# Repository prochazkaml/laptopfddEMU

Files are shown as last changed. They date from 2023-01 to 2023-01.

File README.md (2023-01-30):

# laptopfddEMU
AVR based laptop floppy drive emulator

Consists of 2 MCUs:
- ATmega328PB - runs the actual floppy drive emulator
- ATmega16A - serves as a serial terminal, interfaces to 3x 7-segment displays and 5 buttons

The PCB design with the ATmega328PB (TQFP32) is available in the [kicad](/kicad) directory
(note: the design is bad, the electrolytic cap needs to be as close to the MCU as possible, the current placement causes unexpected issues where the MCU resets randomly - 
just solder another cap directly to the MCU's legs from the programmer/serial side, as you've got nice big pads there).

The "PCB design" with the ATmega16A (DIP40) was improvised and cut out on a piece of raw copper PCB with a knife. No designs available for that, I'm afraid.

Apologies for the lack of documentation on this project, but I was improvising almost everything (as I needed to get this project done extra quick)
and did not keep track of progress very well. Consider building this only if you feel brave enough for it.

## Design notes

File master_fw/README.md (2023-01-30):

# fddEMU
An AVR (atmega328p) based floppy drive emulator for PC
<br>

<br>
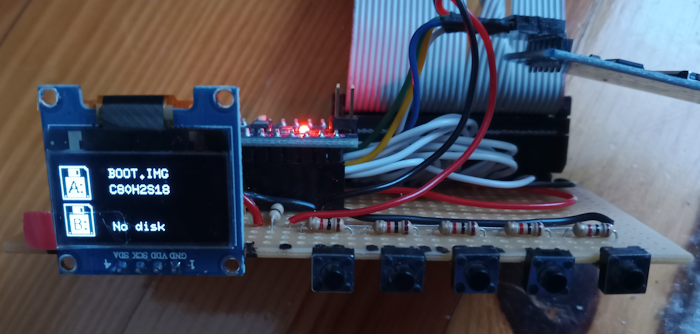
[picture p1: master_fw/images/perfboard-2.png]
fddEMU on perfboard

<br>
<br>
fddEMU is a DIY floppy drive emulator. You can immediately begin testing fddEMU on serial terminal with an arduino nano, an SD adapter that converts 5 volts arduino power supply and signals to 3.3 volts suitable for SD card, an SD card,  and some jumper cables. 
Standalone (using without usb serial connection) require SSD1306 i2c screen, buttons and a 5 volts power supply.
<br><br>

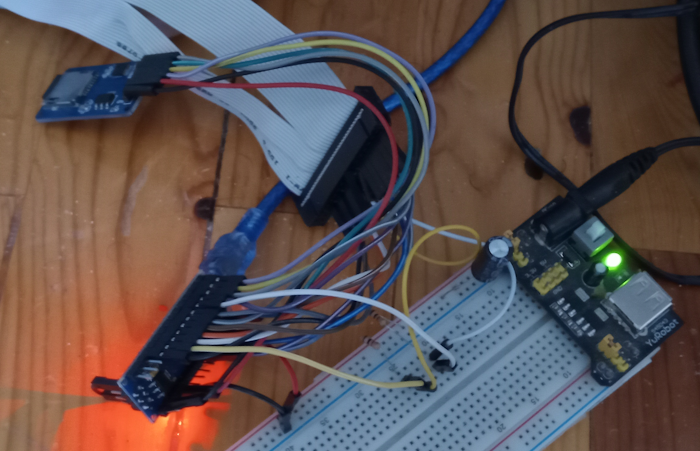
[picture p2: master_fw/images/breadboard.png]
fddEMU on breadboard

<br><br>

**A very compact and configurable PCB design for fddEMU (created by @ikonko)**<br>
Please check [documentation and photos for compact PCB](/master_fw/images/ikonko) for detailed explanation and configuration options. Gerber files are available in [hardware](/hardware) folder.
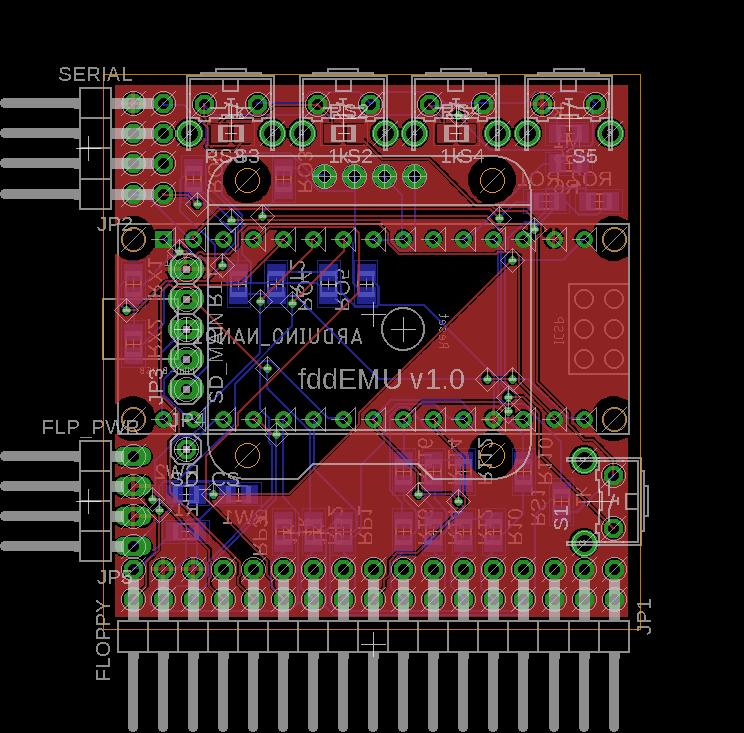
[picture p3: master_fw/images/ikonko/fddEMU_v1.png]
Compact multilayered pcb

<br><br>

**Limitations**
<br>
* fddEMU is not an cycle exact floppy emulator , it is more of a hack (it's a bit slower than actual fdd) but it works because floppy controllers have sensible timeouts and we take advantage of that.
* fddEMU uses MFM encoding (used by HD and DD disks) so there is no FM encoding (used by SD disks) support as of now. But it is possible to implement FM encoding.
* fddEMU uses raw floppy images (images prepared with dd or rawread) does not require or use a MFM file. Converts raw image sectors to MFM on the fly using [ArduinoFDC](https://github.com/dhansel/ArduinoFDC) library.
* fddEMU supports fixed sector size of 512 bytes, other sector sizes are not supported.
* Requires a Floppy Drive Controller (FDC) on the PC side to communicate so it probably wont work with an Amiga.
<br><br>

**Hardware (Required)**
* Arduino Nano or Arduino Pro Micro (UNO will do but button inputs require ADC7, use serial commands instead)
* Micro SD card adapter (converts 5 volts arduino power supply and signals to 3.3 volts)
* A micro SD card (formatted FAT16/32, floppy images in root directory)
* Two 1kOhm resistors for Step (pin 20 of floppy connector) and WriteData (pin 22 of floppy connector). Atmega's internal pullups are not sufficicient for parasitic capacitance of long floppy drive cable
* Male to female jumper wires (for connecting arduino nano pins to FDC ribbon cable)
* Male to male jumper wires (for pullup on step and readdata pins)
<br>

**Hardware (Optional)**
* 0.96" i2c OLED (SSD1306) screen (for output)
* 4 or 5 1kOhm resistors (for making ADC buttons)
* 1 100kOhm resistor (ADC7 has no pullup, so an external pullup required)
* 4 or 5 push buttons (required for ADC input obviously)
* 5 volts power supply (Computer PSU 5v pins or an external PSU can be used)
* Female to female jumper wires (for connecting SD adapter to arduino nano)
* Breadboard or perfboard (for placing pullups and ADC buttons)
<br><br>

**Pin mapping (single drive)**
Arduino Pro Micro   |Arduino Nano   |FDD Ribbon Cable
--------------------|---------------|----------------------
GND                 |GND		    |1	(GND)
RX (PD2)            |D2 (PD2)       |20	(Step pulse)
TX (PD3)            |D3	(PD3)		|18	(Direction)
8  (PB4)            |D4	(PD4)		|16	(Motor on B)
10 (PB6)            |D5	(PD5)		|12	(Drive Select B)
5  (PC6)            |D6	(PD6)		|32	(Select head)
6  (PD7)            |D7	(PD7)		|8	(Index pulse)
4  (PD4)            |D8	(PB0)		|22	(Write data)
9  (PB5)            |D9	(PB1)		|30	(Read data)
7  (PE6)            |A0	(PC0)		|24	(Write enable)
A3 (PF4)            |A1	(PC1)		|26	(Track zero)
24 (PD5 - TXLED)    |A2	(PC2)	    |28	(Write protect)
A1 (PF6)            |A3	(PC3)		|34	(Disk changed)

<br>

**Pin mapping (dual drive)**
Arduino Pro Micro   |Arduino Nano   |FDD Ribbon Cable
--------------------|---------------|----------------------
GND                 |GND		    |1	(GND)
RX (PD2)            |D2 (PD2)       |20	(Step pulse)
TX (PD3)            |D3	(PD3)		|18	(Direction)
8  (PB4)            |D4	(PD4)		|14	(Drive Select A)
10 (PB6)            |D5	(PD5)		|12	(Drive Select B)
5  (PC6)            |D6	(PD6)		|32	(Select head)
6  (PD7)            |D7	(PD7)		|8	(Index pulse)
4  (PD4)            |D8	(PB0)		|22	(Write data)
9  (PB5)            |D9	(PB1)		|30	(Read data)
7  (PE6)            |A0	(PC0)		|24	(Write enable)
A3 (PF4)            |A1	(PC1)		|26	(Track zero)
24 (PD5 - TXLED)    |A2	(PC2)	    |28	(Write protect)
A1 (PF6)            |A3	(PC3)		|34	(Disk changed)

<br>

**Micro SD Adapter connections**
Arduino Pro Micro   |Arduino Nano   |Micro SD adapter
--------------------|---------------|-------------------
A0 (PF7)            |D10 (PB2)  	|CS
16 (PB2)            |D11 (PB3)	    |MOSI
14 (PB3)            |D12 (PB4)		|MISO
15 (PB1)            |D13 (PB5)		|SCK
VCC                 |5V             |VCC
GND                 |GND            |GND

<br>

**0.96" OLED SSD1306 connections**
Arduino Pro Micro   |Arduino Nano   |0.96" OLED SSD1306
--------------------|---------------|-------------------
GND                 |GND            |GND
VCC                 |5V             |VCC
2  (PD1)			|A4			    |SDA
3  (PD0)			|A5			    |SCL

<br><br>

**Resistor ladder for ADC buttons**
<br>
Connected to pin A7 (ADC7) on Arduino Nano or pin A2 (PF5) on Arduino Pro Micro
<br>
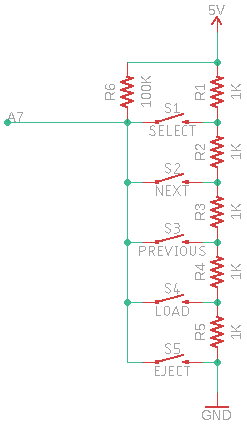
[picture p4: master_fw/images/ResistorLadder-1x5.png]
Resistor Ladder 1x5

<br><br>

**Firmware**
<br>
Download with submodules(u8glib & lufa): `git clone https://github.com/acemielektron/fddEMU --recursive`<br>
If not downloaded with recursive option run (in fddEMU folder): `git submodule update --init --recursive`<br>
Current Makefile assumes avr-gcc and avr-binutils are installed and are in the path, 
avr specific includes are in "/usr/avr/include" (arch) or "/usr/lib/avr/include" (ubuntu) <br>
run `make` to build fddEMU.hex with default options.
<br>
**build options:**
* *GUI:* enables graphical user interface on OLED screen and ADC buttons (enabled default by Makefile). 
* *SERIAL:* enables serial user interface and serial commands.
* *VFFS:* enables virtual disk.
* *DEBUG:* enables debug output on serial.
* *FLIP:* flips the image on OLED screen 180 degrees (enabled default by Makefile).
* *WDT:* enables watchdog timer (enabled default by Makefile).<br><br>
These build options could either be switched on and off from Makefile or commandline 
(eg.: `make DUAL=1 GUI=1 VFFS=1 SERIAL=0 DEBUG=0`).<br>
Flashing the mcu could also be done by Makefile. `make flash` programs "fddEMU.hex" to 
default serial port "/dev/ttyUSB0". If you want to use another serial port assign it to 
PORT variable (eg.: `make flash PORT=/dev/ttyUSB2`).

**Note:** Due to larger bootloader on Atmega32U4 and added code overhead for USB-Serial all features of fddEMU will be avaialble on Atmega32U4

***Warning:*** *Writing > 28K (28672 bytes) firmware to Arduino Pro Micro results in bootloader being overwritten and requires reprogramming the bootloader using external programmer (eg. USBASP). Please check output of avr-size at the end of make process and make sure it is < 28K.*
<br><br>

**How to use**<br>
* fddEMU looks for a boot record on "sector 0" of the image. If the boot record reports that the image is formatted as "FAT1?", sector size is 512, number of heads is 2 and number of tracks and number of sectors are less than 255 the image file is loaded with the settings provided by the boot record. To be able to read these custom FAT12 images host system should support provided number of tracks and sectors. If there is no boot record file size is compared to the standart floppy sizes (1.44M, 1.2M, 720K and 360K), if file size matches one of these sizes it is loaded as raw image.
* Image file must be contiguous for fddEMU to be able to load, if the file is not contiguous an error message will be shown and loading will fail.
* Contiguity check would take long for large files (> 2MB) during this check fddEMU can not be used.
* For booting a host system, on startup fddEmu looks for "BOOT.IMG" on SD card. If there is a "BOOT.IMG" on the SD card fddEMU tries to load this file to drive A. 
* if image file has "read only" attribute set, fddEMU will report "Write Protected" to host system.
* To protect OLED screen fddEMU will put screen to sleep after some idle time, press "S1" (SELECT) button or "S" key inside serial terminal to wake screen up.
* When host is reading/writing one of the emulated drives, BUSY message will be shown on screen and serial, during this time fddEMU will not respond to input. *Warning: fddEMU will not put the screen to sleep while drive is active. If there is a hardware or software problem causing an emulated drive to go continuously active, OLED screen might get damaged.*
<br><br>

**How to use (GUI button interface)**
* S1: Load Virtual Disk
* S2: Next
* S3: Previous
* S4: Open file selection Menu / Load selected file
* S5: Eject selected disk / Cancel loading file
<br>
On the main screen, drive 0 "A" and -if enabled- drive 1 "B" are displayed. To use any of the functions a drive must first be selected through "S2" or "S3" buttons.<br>
After a drive is selected:<br>
"S1" button: in main status screen, if virtual disk is enabled, loads the virtual disk to selected drive.<br>
"S2" button: in main status screen selects drive down, in file selection menu selects file down.<br>
"S3" button: in main status screen selects drive up, in file selection menu selects file up.<br>
"S4" button: in main status screen opens file selection menu, in file selection menu loads the selected image file to the selected drive.<br>
"S5" button: in main status screen ejects image file loaded to the selected drive, in file section menu cancels file selection and returns to main status screen.
<br><br>

**How to use (Serial interface)**
<br>
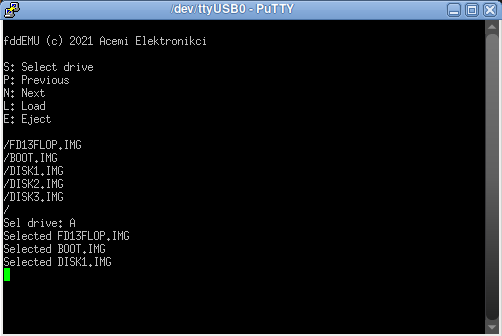
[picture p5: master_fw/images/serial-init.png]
initial serial output

<br><br>
fddEMU serial interface is used through keys 
* S: Select
* N: Next file
* P: Previous file
* L: Load selected file
* E: Eject selected disk / Cancel loading file
<br>
To use any of the functions a drive must first be selected through "S" key then serial terminal will report "Sel drive: A" or if drive B is selected "Sel drive: B".<br>
After a drive is selected:<br>
"S" key: shows serial status information and selects next drive.<br>
"N" key: selects next image file. If virtul disk is enabled and if the last file in the directory is reached selects virtual disk .<br>
"P" key: selects the previous image file. If the first file is selected, this file is reselected.<br>
"L" key: loads selected image file to the selected drive.<br>
"E" key: ejects image file loaded to selected drive. If pressed during file selection, cancels file selection.
<br><br>

**How to use through host system (Virtual Disk)**
<br>
-if virtual disk (VFFS) is enabled and loaded- Virtual disk root directory contains a "DISKS" directory, a "DRVA.TXT" file and if DUAL drives enabled a "DRVB.TXT" file. If an SD card is inserted "DISKS" directory contains the file listing of inserted SD card's root directory otherwise it will be empty. "DRVA.TXT" would contain name of the image file loaded the "drive 0" and "DRVB.TXT" would contain name of the image file loaded to "drive 1". Writing the name of an image file to either "DRVA.TXT" or "DRVB.TXT" would result loading requested image file to respective emulated drive upon host releasing the drive. However disk write cache might interfere writing into these files and a cache flush might be required.
<br><br>

**Troubleshooting**
* To test fddEMU or any other floppy drive emulator a Floppy Drive Controller (FDC) is very useful. Unfortunately new computers usually don't come with a FDC. Thankfully we already have a very good FDC that generates the precise debug information we need: the [ArduinoFDC](https://github.com/dhansel/ArduinoFDC). A direct pin to pin connection from fddEMU to ArduinoFDC works, if using shorter jumper wires external pullups are not necessary.
* If using a floppy drive ribbon cable make sure of external pullup resistors to +5V on Step (Pin 20 on floppy connector) and WriteData (pin 22 on floppy connector) pins.
* If WiteData pin (pin 22 on floppy connector) is disconnected or does not have sufficient external pullup fddEMU might hang up while reading data from host, which might cause a static image on screen. To protect the screen currently a watchdog timer of 8 seconds is set (which is the longest duration for watchdog timer). If mcu (arduino) can't access SD card after reset remove the sd card, wait a few seconds, reinsert the SD card then reset the arduino.

**Acknowledgements**
<br>
* [ArduinoFDC](https://github.com/dhansel/ArduinoFDC) by [David Hansel](https://github.com/dhansel). fddEMU uses a modified ArduinoFDC library renamed to avrFlux for communicating with FDC.
* [Petit FAT FS](https://github.com/greiman/PetitFS) by [Chan](http://elm-chan.org/fsw/ff/00index_p.html) adapted for hardware SPI by [Bill Greiman](https://github.com/greiman). fddEMU uses a modified Petit FAT FS.
* [rjhcoding.com/avrc-sd-interface](http://rjhcoding.com/avrc-sd-interface-1.php) Great tutorial for using SD card with AVR.
* [u8glib](https://github.com/olikraus/u8glib) Very useful for incorporating SSD1306 and can easily be used with various displays.
* [lufa](https://github.com/abcminiuser/lufa) Lightweight USB Framework for AVRs
<br><br>

**Releases**
<br>
* [fddEMU releases](https://github.com/acemielektron/fddEMU/releases)
<br><br>

**Note:**  Please report any errors on [github issues for fddEMU](https://github.com/acemielektron/fddEMU/issues). Suggestions for improvements and feedback could be posted on [discussions](https://github.com/acemielektron/fddEMU/discussions) or [fddEMU blog page](http://acemielektronikci.blogspot.com/2021/10/fddemu-disket-surucu-emulatoru.html) Although the blog page is in turkish, feel free to write comments either in turkish or english.
<br><br>

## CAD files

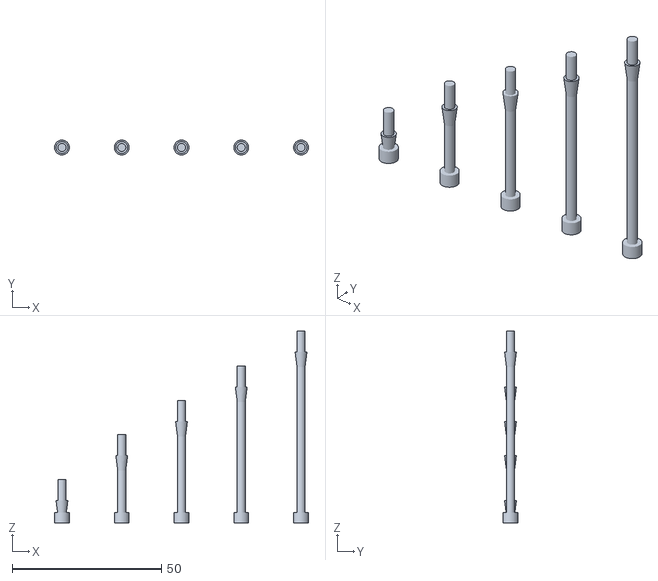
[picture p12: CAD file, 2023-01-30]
3d/floppyemubutton.stl
85.0 x 5.00 x 64.2

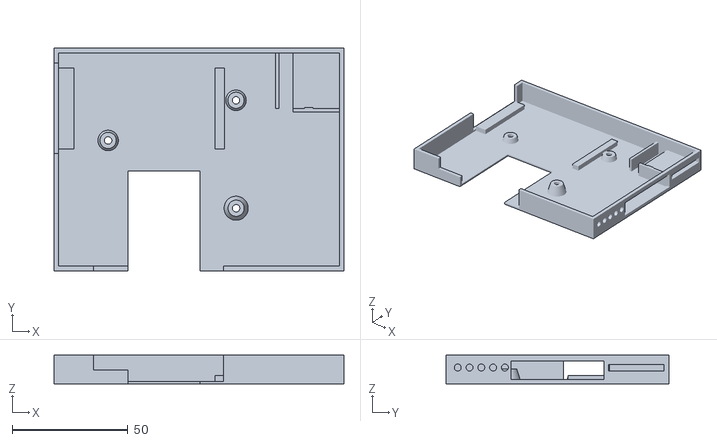
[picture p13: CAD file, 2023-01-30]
3d/floppyemu.stl
125.0 x 96.0 x 12.5

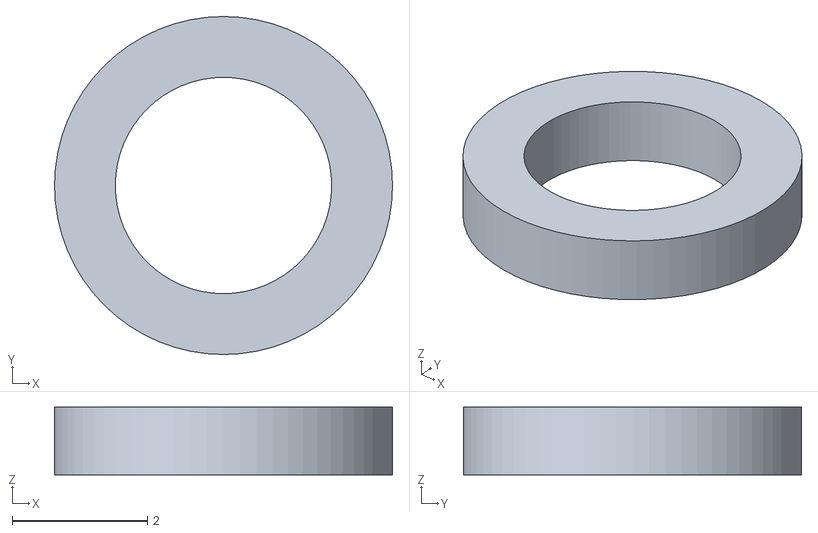
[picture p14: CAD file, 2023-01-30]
3d/floppyemuscrew.stl
5.00 x 5.00 x 1.00

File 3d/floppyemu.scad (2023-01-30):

led_w = 40;
led_h = 8;
led_z = 2;

sd_w = 24;
sd_h = 2.8;
sd_d = 32 - 4;
sd_z = 5.7;

sd_stop_d = 1.5;

sd_pin_d = 6;

body_w = 125;
body_d = 96;

pcb_w = 83.0580;
pcb_d = 34.9200;

pcb_off_x = 2;
pcb_off_y = 8.5;

pcb_front_standoff_w = 6.6040;
pcb_back_standoff_x = 11.6000;
pcb_back_standoff_w = 4.0000;

pcb_h1_x = 21.3360;
pcb_h1_y = 3.6360;

pcb_h2_x = pcb_w - 6.6040;
pcb_h2_y = pcb_d - 13.9700;

dpcb_cutout_x = 32;
dpcb_cutout_w = 31;
dpcb_cutout_h = 43;

dpcb_screw_x = 46.5;
dpcb_screw_y = 27;

$fn = 64;

module maincutout() {
	difference() {
		union() {
			translate([2, 2, 1]) cube([body_w - 4, body_d - 4, 12.51]);
			translate([17, -.01, 3]) cube([body_w - 17 - 52, 2.02, 12.51]);
			translate([dpcb_cutout_x + dpcb_cutout_w - .01, -.01, 1]) cube([(body_w - dpcb_cutout_x - dpcb_cutout_w) - 51.99, 2.02, 10]);
		}
		children();
	}
	
/*	difference() {
		for(i = [0 : 10]) hull() {
			translate([10, 8 + i * (body_d - 16) / 10]) cylinder(h = 2.01, d = 5, center = true);
			
			translate([body_w - 8, 8 + i * (body_d - 16) / 10]) cylinder(h = 2.01, d = 5, center = true);
		}
		
		children();
	}*/
}
/*

translate([pcb_off_x, body_d - pcb_off_y - pcb_d, 3.75]) difference() {
	cube([pcb_w, pcb_d, 1.6]);
	translate([pcb_h1_x, pcb_h1_y]) cylinder(d = 3.2, h = 4, center = true);
	translate([pcb_h2_x, pcb_h2_y]) cylinder(d = 3.2, h = 4, center = true);
}
*/

difference() {
	cube([body_w, body_d, 12.5]);
	
	// PCB cutout
	translate([-.01, body_d - pcb_off_y - pcb_d - 2, 2]) cube([2.02, pcb_d + 4, 20]);

	// Daughter PCB cutout (otherwise it wouldn't fit)
	translate([dpcb_cutout_x, -.01, -.01]) cube([dpcb_cutout_w, dpcb_cutout_h, 12.51]);
	
	maincutout() {
		// PCB front standoff
		translate([pcb_off_x, body_d - pcb_off_y - pcb_d]) cube([pcb_front_standoff_w, pcb_d, 7.5 / 2]);

		// PCB back standoff
		translate([pcb_off_x + pcb_w - pcb_back_standoff_x - pcb_back_standoff_w, body_d - pcb_off_y - pcb_d]) cube([pcb_back_standoff_w, pcb_d, 7.5 / 2]);
		
		// PCB screw posts
		translate([pcb_off_x + pcb_h1_x, body_d - pcb_off_y - pcb_d + pcb_h1_y]) cylinder(d1 = 12, d2 = 7, h = 7.5, center = true);
		
		translate([pcb_off_x + pcb_h2_x, body_d - pcb_off_y - pcb_d + pcb_h2_y]) cylinder(d1 = 12, d2 = 7, h = 7.5, center = true);
		
		// Daughter PCB screw post
		translate([body_w - dpcb_screw_x, dpcb_screw_y]) cylinder(d1 = 15, d2 = 7, h = (8 - 1.6) * 2, center = true);
		
		// SD bottom plate
		translate([body_w - sd_d + sd_pin_d, body_d - 2 - sd_w, 0]) cube([sd_d - sd_pin_d, sd_w, sd_z]);
		
		// SD back wall
		translate([body_w - sd_d - sd_stop_d, body_d - 2 - sd_w, 0]) cube([sd_stop_d, sd_w, sd_z + sd_h]);
		
		// SD side wall
		translate([body_w - sd_d + sd_pin_d, body_d - 2 - sd_w - sd_stop_d, 0]) difference() {
			cube([sd_d - sd_pin_d, sd_stop_d, sd_z + sd_h]);

			// Wire cutout

//			translate([sd_stop_d, -.01, 0]) cube([sd_pin_d, (body_d - 2 - sd_w) - (body_d / 2 + 40 / 2) + .02, sd_z]);
		}
		
		// SD lock notch
		translate([body_w - sd_d + 10.9, body_d - 2 - sd_w, 0]) cube([3.75, .5, sd_z + sd_h]);
	}
	
	// PCB screw holes
	translate([pcb_off_x + pcb_h1_x, body_d - pcb_off_y - pcb_d + pcb_h1_y]) {
		cylinder(d = 3.2, h = 7.51, center = true);
		cylinder(d = 6.5, $fn = 6, h = 5.5, center = true);
	}
	
	translate([pcb_off_x + pcb_h2_x, body_d - pcb_off_y - pcb_d + pcb_h2_y]) {
		cylinder(d = 3.2, h = 7.51, center = true);
		cylinder(d = 6.5, $fn = 6, h = 5.5, center = true);		
	}

	// Daughter PCB screw hole
	translate([body_w - dpcb_screw_x, dpcb_screw_y]) {
		cylinder(d = 3.2, h = (8 - 1.6) * 2.01, center = true);
		cylinder(d = 6.5, $fn = 6, h = 10, center = true);		
	}
	
	// LED display front cutout
	translate([body_w - 2.01, body_d / 2 - led_w / 2, led_z]) cube([2.02, led_w, led_h]);
	
	// SD card front cutout
	translate([body_w - 2.01, body_d - 2 - sd_w, sd_z]) cube([2.02, sd_w, sd_h]);
	
	// Button front cutout
	for(i = [0 : 4]) translate([body_w - 1, 5 + i * 2.54 * 2, sd_z + sd_h / 2]) rotate([0, 90, 0]) cylinder(h = 2.01, center = true, d = 3);
	
//	cube([94, body_d, 13]);
//	cube([120, 65, 13]);
}

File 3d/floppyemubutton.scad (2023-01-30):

$fn = 64;

sizes = [7.5, 22.6, 34, 45.5, 57.2];

for(i = [0 : len(sizes) - 1]) translate([i * 20, 0]) {
	difference() {
//		cylinder(h = sizes[i], d = 5);
		cylinder(h = 3.5, d = 5);
		translate([0, 0, -.01]) cylinder(h = 2.5, d = 3.75);
	}
	
	translate([0, 0, sizes[i] - 5]) cylinder(h = 5, d1 = 2.7, d2 = 4);
	
	translate([0, 0, 3.5]) cylinder(h = sizes[i] + 3.5, d = 2.7);
}

//translate([0, 0, 3.5]) cylinder(h = 59 + 1.5, d = 2.8);
//translate([0, 0, 3.5]) cylinder(h = 35.4 + 1.5, d = 2.8);

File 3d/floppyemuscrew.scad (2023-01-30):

$fn = 64;

difference() {
	cylinder(h = 1, d = 5, center = true);
	cylinder(h = 1.01, d = 3.2, center = true);
}

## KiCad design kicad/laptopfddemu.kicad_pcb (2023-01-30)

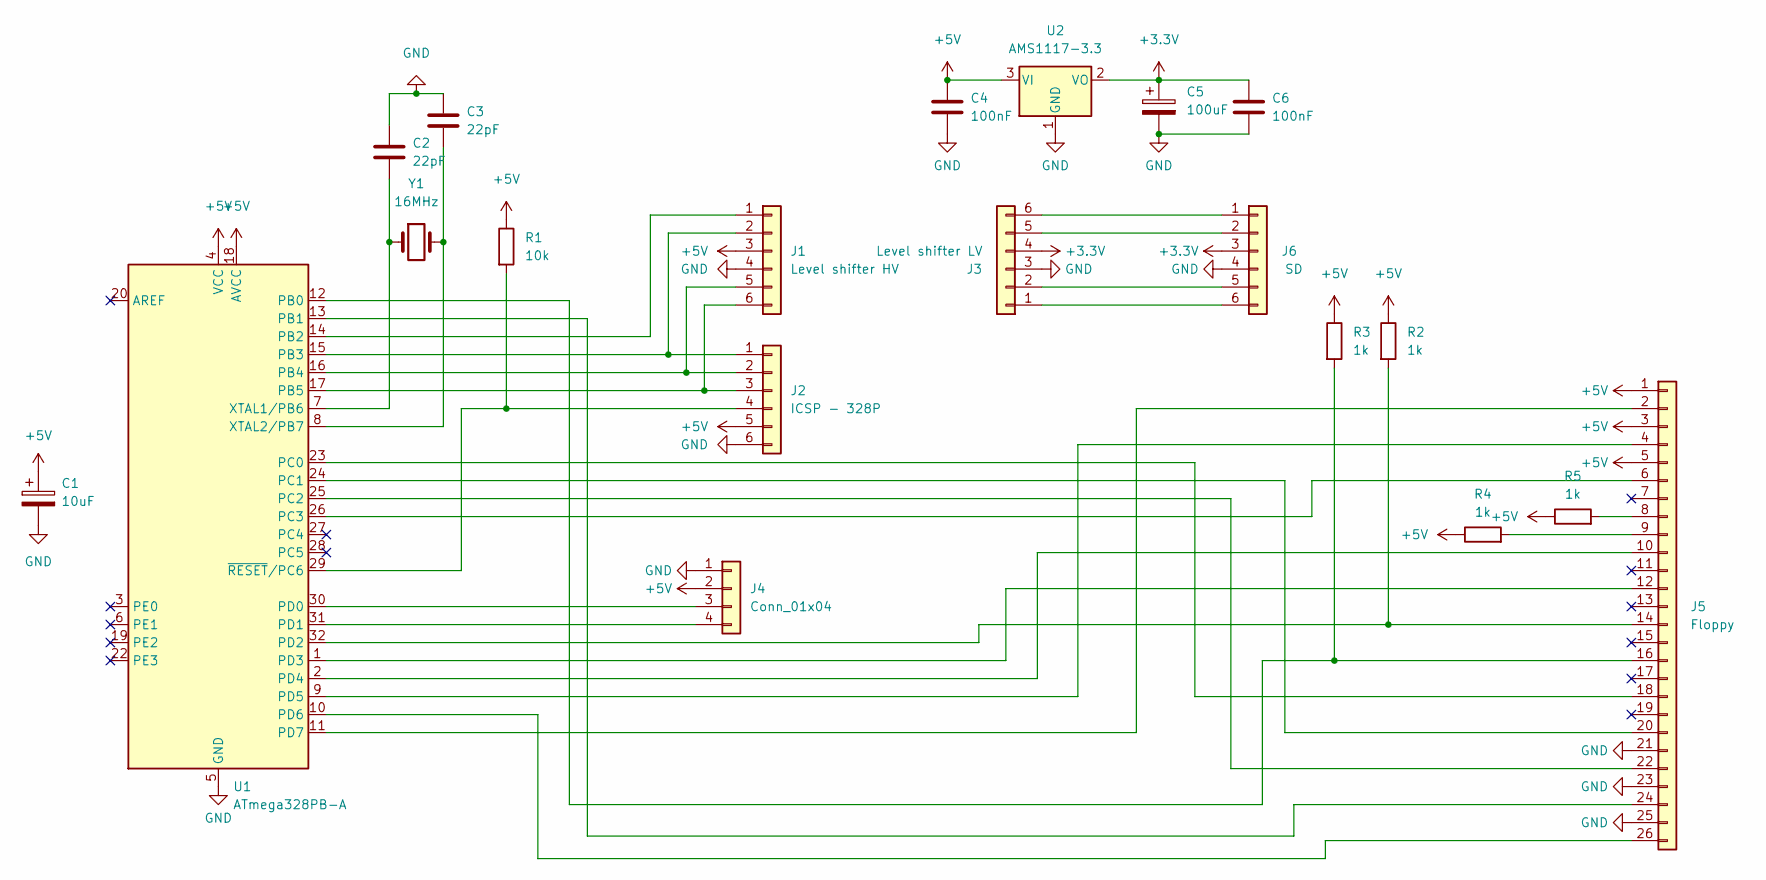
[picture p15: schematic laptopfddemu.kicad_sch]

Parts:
C1: 10uF; CP_Radial_D5.0mm_P2.50mm
C2, C3: 22pF; C_Disc_D7.0mm_W2.5mm_P5.00mm
C4, C6: 100nF; C_Disc_D7.0mm_W2.5mm_P5.00mm
C5: 100uF; CP_Radial_D5.0mm_P2.50mm
J1: Level shifter HV; PinHeader_1x06_P2.54mm_Vertical
J2: ICSP - 328P; PinHeader_1x06_P2.54mm_Vertical
J3: Level shifter LV; PinHeader_1x06_P2.54mm_Vertical
J4: Conn_01x04; PinHeader_1x04_P2.54mm_Vertical
J5: Floppy; TE_2-84953-6_1x26-1MP_P1.0mm_Horizontal
J6: SD; PinHeader_1x06_P2.54mm_Vertical
R1: 10k; R_Axial_DIN0207_L6.3mm_D2.5mm_P10.16mm_Horizontal
R2, R3, R4, R5: 1k; R_Axial_DIN0207_L6.3mm_D2.5mm_P10.16mm_Horizontal
U1: ATmega328PB-A; TQFP-32_7x7mm_P0.8mm
U2: AMS1117-3.3; SOT-223-3_TabPin2
Y1: 16MHz; Crystal_HC49-U_Vertical

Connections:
+3.3V: C5.1, C6.1, J3.4, J6.3, U2.2 (VO)
+5V: C1.1, C4.1, J1.3, J2.5, J4.2, J5.1, J5.3, J5.5, R1.1, R2.1, R3.1, R4.1, R5.1, U1.4 (VCC), U1.18 (AVCC), U2.3 (VI)
GND: C1.2, C2.1, C3.1, C4.2, C5.2, C6.2, J1.4, J2.6, J3.3, J4.1, J5.21, J5.23, J5.25, J5.MP, J6.4, U1.5 (GND), U1.21 (GND), U2.1 (GND)
unnamed: C2.2, U1.7 (XTAL1/PB6), Y1.1
unnamed: C3.2, U1.8 (XTAL2/PB7), Y1.2
unnamed: J1.1, U1.14 (PB2)
unnamed: J1.2, J2.1, U1.15 (PB3)
unnamed: J1.5, J2.2, U1.16 (PB4)
unnamed: J1.6, J2.3, U1.17 (PB5)
unnamed: J2.4, R1.2, U1.29 (~RESET/PC6)
unnamed: J3.1, J6.6
unnamed: J3.2, J6.5
unnamed: J3.5, J6.2
unnamed: J3.6, J6.1
unnamed: J4.3, U1.30 (PD0)
unnamed: J4.4, U1.31 (PD1)
unnamed: J5.2, U1.11 (PD7)
unnamed: J5.4, U1.9 (PD5)
unnamed: J5.6, U1.26 (PC3)
unnamed: J5.8, R5.2
unnamed: J5.9, R4.2
unnamed: J5.10, U1.2 (PD4)
unnamed: J5.12, U1.1 (PD3)
unnamed: J5.14, R2.2, U1.32 (PD2)
unnamed: J5.16, R3.2, U1.12 (PB0)
unnamed: J5.18, U1.23 (PC0)
unnamed: J5.20, U1.24 (PC1)
unnamed: J5.22, U1.25 (PC2)
unnamed: J5.24, U1.13 (PB1)
unnamed: J5.26, U1.10 (PD6)

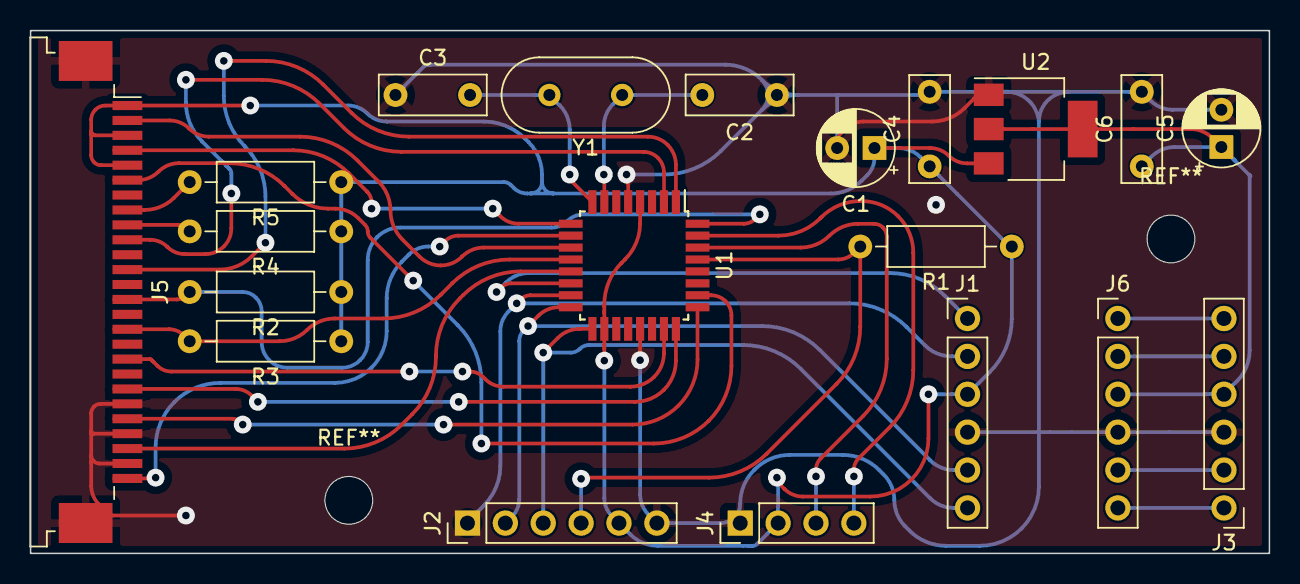
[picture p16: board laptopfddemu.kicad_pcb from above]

Board: 2 copper layers, 83.1 x 35.1 mm, 20 parts (0 on the bottom side), 30 nets.

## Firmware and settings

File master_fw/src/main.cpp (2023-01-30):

// -----------------------------------------------------------------------------
// fddEMU "Floppy Disk Drive Emulator"
// Copyright (C) 2021 Acemi Elektronikci
//
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

#include "fddEMU.h"
#include "FloppyDrive.h"
#include "serial/SerialUI.h"
#include <avr/io.h>
#include "petitfs/pff.h"
#include "DiskFile.h"

int main(void)
{
#ifdef DDRE
	DDRE = 0;
	PORTE = 0xF;
#endif

#if ENABLE_WDT
	wdt_enable(WDTO_8S);
#endif  //ENABLE_WDT
#if ENABLE_SERIAL || DEBUG
	Serial.init(115200);
	ser.intro();
#endif //ENABLE_SERIAL || DEBUG
//	if (sdfile.sdInitialized)
//		drive[0].load((char *)s_bootfile);   //if there is "BOOT.IMG" on SD load it
#if ENABLE_VFFS
//	else
//		drive[0].loadVirtualDisk();
#endif //ENABLE_VFFS
	for(;;)
	{
	#if ENABLE_WDT
		wdt_reset();
	#endif //ENABLE_WDT
		if (ds.isDrvChanged())
		{
			uint8_t selectedDrive = ds.getDriveSel();
		#if ENABLE_GUI
			disp.showDriveBusy(selectedDrive);
		#endif //ENABLE_GUI
		#if ENABLE_SERIAL || DEBUG
			Serial.print_P(str_busy); //very short message, take too long and get drive read errors
		#endif //#if ENABLE_SERIAL || DEBUG
			drive[selectedDrive - 1].run();
		#if ENABLE_VFFS
			vffs.loadImage(); //check if a drive is flagged for vffs load and load if it is
		#endif //ENABLE_VFFS
		#if ENABLE_GUI
			disp.showDriveIdle();
		#endif //ENABLE_GUI
		#if ENABLE_SERIAL || DEBUG
			Serial.print_P(str_idle);
		#endif //ENABLE_SERIAL || DEBUG
		}
	#if ENABLE_SERIAL
		if (rxReady) ser.readRx();
	#endif //ENABLE_SERIAL
	#if ENABLE_GUI
		if (adcReady) disp.buttonAction(abtn.read());
		disp.update();
	#endif //ENABLE_GUI
	}
}

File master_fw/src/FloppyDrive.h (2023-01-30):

// -----------------------------------------------------------------------------
// This file is part of fddEMU "Floppy Disk Drive Emulator"
// Copyright (C) 2021 Acemi Elektronikci
//
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
#ifndef FLOPPYDRIVE_H
#define FLOPPYDRIVE_H

#include "FloppyDisk.h"
#include <stdint.h>

#if defined (__AVR_ATmega328P__) || defined (__AVR_ATmega328PB__)
// -------------------------------  Pin assignments for Arduino UNO/Nano/Pro Mini (Atmega328p)  ------------------------------
//PORTD
#define PIN_STEP      2
#define REG_STEP			PIND
#define PIN_STEPDIR   3
#define REG_STEPDIR		PIND
#define PIN_MOTORA    4
#define REG_MOTORA		PIND
#define PIN_SELECTA   5
#define REG_SELECTA		PIND
#define PIN_SIDE      6
#define REG_SIDE			PIND
#define PIN_INDEX     7
#define DDR_INDEX			DDRD

//PORTB
#define PIN_READDATA  0
#define DDR_READDATA	DDRB
#define PIN_WRITEDATA 1
#define DDR_WRITEDATA DDRB
//rest of PORTB pins are SPI

//PORTC
#define PIN_WRITEGATE 0
#define REG_WRITEGATE PINC
#define PIN_TRACK0    1
#define DDR_TRACK0 		DDRC
#define PIN_WRITEPROT 2
#define DDR_WRITEPROT DDRC
#define PIN_DSKCHANGE 3
#define DDR_DSKCHANGE DDRC


// -------------------------------  Pin assignments for Arduino UNO/Nano/Pro Mini (Atmega328p)  ------------------------------
#elif defined (__AVR_ATmega32U4__)
// -------------------------------  Pin assignments for Arduino (Atmega32U4)  ------------------------------
//PORTD PD0(SCL) and PD1(SDA) I2C pins (D2 and D3 on pro micro)
//PORTB PB0(SS), PB1(SCK), PB2(MISO), PB3(MOSI) SPI pins (D17, D15, D14, D16)  D17->TX led

//Unchangeable pins ICP&OCP for timer1
#define PIN_READDATA    4   //PD4 must be pin4 (ICP for timer1)
#define DDR_READDATA		DDRD
#define PIN_WRITEDATA   5   //PB5 must be pin9 (OCP for timer1)
#define DDR_WRITEDATA		DDRB
//Pin Change Interrupt pins
#define PIN_MOTORA      4   //PB4-PCINT4-pin8
#define REG_MOTORA			PINB
#define PIN_SELECTA     6   //PB6-PCINT6-pin10
#define REG_SELECTA			PINB
//External Interrupt pins
#define PIN_STEP        2   //PD2-INT2-RX1 will use external interrupt 2
#define REG_STEP				PIND
//Changeable pins
#define PIN_STEPDIR     3   //PD3-INT3-TX1
#define REG_STEPDIR			PIND
#define PIN_SIDE        6   //PC6-pin5
#define REG_SIDE				PINC
#define PIN_INDEX       7   //PD7-pin6
#define DDR_INDEX				DDRD
#define PIN_WRITEGATE   6   //PE6-INT6-pin7
#define REG_WRITEGATE		PINE
#define PIN_TRACK0      4   //PF4-pinA3
#define DDR_TRACK0			DDRF
#define PIN_WRITEPROT   5   //PD5-pin24-TXLED
#define DDR_WRITEPROT		DDRD
#define PIN_DSKCHANGE   6   //PF6-pinA1
#define DDR_DSKCHANGE		DDRF
//SS pin for SD card is PF7-pinA0 for atmega32u4 (Arduino pro micro)
//SS pin is set in "pffArduino.h" to change the pin
//also changing the macros in "pffArduino.h" is required.

// -------------------------------  Pin assignments for Arduino (Atmega32U4)  ------------------------------
#endif //defined (__AVR_ATmega32U4__)

//Output commands
#define SET_INDEX_LOW()    (DDR_INDEX |= (1 << PIN_INDEX))
#define SET_INDEX_HIGH()   (DDR_INDEX &= ~(1 << PIN_INDEX))
#define SET_TRACK0_LOW()    (DDR_TRACK0 |= (1 << PIN_TRACK0))
#define SET_TRACK0_HIGH()   (DDR_TRACK0 &= ~(1 << PIN_TRACK0))
#define SET_DSKCHANGE_LOW()    (DDR_DSKCHANGE |= (1 << PIN_DSKCHANGE))
#define SET_DSKCHANGE_HIGH()   (DDR_DSKCHANGE &= ~(1 << PIN_DSKCHANGE))
#define SET_WRITEPROT_LOW()    (DDR_WRITEPROT |= (1 << PIN_WRITEPROT))
#define SET_WRITEPROT_HIGH()   (DDR_WRITEPROT &= ~(1 << PIN_WRITEPROT))

//Inputs
#define IS_WRITE()          ( !(REG_WRITEGATE & (1 << PIN_WRITEGATE)) )
#define SIDE()              (REG_SIDE & (1 << PIN_SIDE))
#define STEPDIR()           (REG_STEPDIR & (1 << PIN_STEPDIR))
#define IS_STEP()           ( !(REG_STEP & (1 << PIN_STEP)) )
#define IS_SELECTA()        ( !(REG_SELECTA & (1 << PIN_SELECTA)) )
#define IS_MOTORA()         ( !(REG_MOTORA & (1 << PIN_MOTORA)) )
//Two drive mode requires SELECT and MOTOR pins combined trough an AND gate
//if two drive mode is enabled SELECTA pin is used for combined SELECTA & MOTORA
//and MOTORA pin is used for combined SELECTB & MOTORB

struct __attribute__((__packed__)) driveControlFlags
{
	uint8_t driveSel : 2;		
	uint8_t trackChanged : 1;
	uint8_t empty : 5;
};

class driveStatus
{
	private:
		volatile struct driveControlFlags f;		
	public:
		driveStatus() {f.driveSel = 0; f.trackChanged = 0;}
		void setTrackChanged() {f.trackChanged = 1;}
		void clrTrackChanged() {f.trackChanged = 0;}
		uint8_t isTrackChanged() {return f.trackChanged;}	
	#if ENABLE_DRIVE_B // Dual drive mode		
		uint8_t isDrive0() {return IS_SELECTA() ? (1 << 0):0;}
		uint8_t isDrive1() {return IS_MOTORA() ? (1 << 1):0;}
	#else // Single drive mode
		uint8_t isDrive0() {return IS_SELECTA() && IS_MOTORA() ? (1 << 0):0;}
		uint8_t isDrive1() {return 0;}			
	#endif // ENABLE_DRIVE_B 		
		uint8_t getDriveSel () {return isDrive1()|isDrive0();}		
		bool isDrvChanged() 
		{
			if (f.driveSel == getDriveSel()) return false;
			else f.driveSel = getDriveSel(); 
			return true;
		}		
};

struct __attribute__((__packed__)) floppySectorHeader
{
	union 
	{
		uint8_t buffer[8];
		struct __attribute__((__packed__)) 
		{
			uint8_t	id;	// sector header id: 0xFE
			uint8_t track; // current cylinder
			uint8_t	side; // current head
			uint8_t	sector;	// current sector: starts at 1
			uint8_t	length; // 0: 128b, 1: 256b, 2: 512b, 3: 1024b
			uint8_t crcHI; // crc / 256
			uint8_t	crcLO; // crc & 255
			uint8_t gap; // first byte of post-header gap: 0x4E

		};
	};
	
};

struct __attribute__((__packed__)) floppySectorData
{
	union 
	{
		uint8_t buffer[1+512+3+3];
		struct __attribute__((__packed__))
		{
			uint8_t	id; // sector data id: 0xFB
			uint8_t	data[512]; //sector data 512 bytes
			uint8_t crcHI; // crc / 256
			uint8_t	crcLO; // crc & 255
			uint8_t gap; // first byte of post-data gap: 0x4E
			uint8_t save[3]; //storage for saving half_sector data			
		};		
	};	
};

class FloppyDrive : public FloppyDisk
{
	private:
		int track;
		int getSectorData(int lba);
		int setSectorData(int lba);

	public:
		FloppyDrive();
		char *diskInfoStr();
		bool load(char *);
		void eject();
		void run();
};

#if ENABLE_DRIVE_B
		#define N_DRIVE 2
#else
		#define N_DRIVE 1
#endif //ENABLE_DRIVE_B

extern volatile uint8_t iFlags; //flags set by interrupt
extern class FloppyDrive drive[N_DRIVE];
extern class driveStatus ds;

#endif //PLOPPYDRIVE_H

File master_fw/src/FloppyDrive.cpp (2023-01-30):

// -----------------------------------------------------------------------------
// This file is part of fddEMU "Floppy Disk Drive Emulator"
// Copyright (C) 2021 Acemi Elektronikci
//
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

#include "fddEMU.h"
#include "FloppyDrive.h"
#include "petitfs/pff.h"
#include "petitfs/diskio.h"
#include "avrFlux/avrFlux.h"
#include "UINotice.h" //msg.error
#include <avr/io.h>
#include <avr/interrupt.h>
#include <avr/wdt.h>
#include <string.h> // for strcat,strcpy,...
#include <stdlib.h> // for itoa

//Global variables
bool pinsInitialized = false;
static struct floppySectorHeader secHeader;
static struct floppySectorData secData;
volatile int8_t iTrack = 0;
class driveStatus ds;

class FloppyDrive drive[N_DRIVE]; //will be used as extern

//Interrupt routines
#if defined (__AVR_ATmega328P__) || defined (__AVR_ATmega328PB__)
ISR(INT0_vect) //int0 pin 2 of port D
#elif defined (__AVR_ATmega32U4__)
ISR(INT2_vect) //int2
#endif //(__AVR_ATmega32U4__)
{
	if (IS_STEP() ) //debounce
		(STEPDIR()) ? --iTrack : ++iTrack;
	ds.setTrackChanged();
}

void initFDDpins()
{
	//To emulate open collector outputs Output pins are set to LOW "0"
	//To write a "1" to output pin, respective pin is set to input
	//To write a "0" to output pin, respective pin is set to output
	pinsInitialized = false;
	cli(); //disable interrupts
#if defined (__AVR_ATmega328P__) || defined (__AVR_ATmega328PB__)
	//Setup Input and Output pins as Inputs
	DDRD &= 0b00000011; //D0 and D1 is RX & TX
	DDRB &= 0b11000000; //B6 & B7 is XTAL1 & XTAL2
	DDRC &= 0b11110000; //C7 is nil, C6 is RST, C4 & C5 is SDA & SCL
	//Assign Output pins LOW "0"
	PORTD &= ~(1 << PIN_INDEX);
	PORTB &= ~(1 << PIN_WRITEDATA);
	PORTC &= ~((1 << PIN_TRACK0)|(1 << PIN_WRITEPROT)|(1 << PIN_DSKCHANGE));
	//Assign Input pins HIGH "1" (Activate Pullups)
	PORTD |= (1 << PIN_MOTORA)|( 1 << PIN_SELECTA);
	PORTD |= (1 << PIN_STEP)|(1 << PIN_STEPDIR)|(1 << PIN_SIDE);
	PORTB |= (1 << PIN_READDATA);
	PORTC |= (1 << PIN_WRITEGATE);
	//Setup External Interrupt
	EICRA &=~((1 << ISC01)|(1 << ISC00)); //clear ISC00&ISC01 bits
	EICRA |= (1 << ISC01); //set ISC01 "falling edge"
	EIMSK |= (1 << INT0); //External Interrupt Mask Register enable INT0
#elif defined (__AVR_ATmega32U4__)
	//Setup Input and Output pins as Inputs
	DDRB |= (1 << PIN_WRITEDATA); //set WRITEDATA as OUTPUT (Not sure it is necessary but datasheet says so)
	DDRB &= ~((1 << PIN_MOTORA)|(1 << PIN_SELECTA)); //PB0 RXLED, PB1 SCK, PB2 MOSI, PB3 MISO, PB4 MOTORA, PB5 OCP1, PB6 SELECTA
	DDRC &= ~(1 << PIN_SIDE); //PC6 SIDE
	DDRD &= ~((1 << PIN_STEP)|(1 << PIN_STEPDIR)|(1 << PIN_READDATA)|(1 << PIN_INDEX)|(1 << PIN_WRITEPROT)); //PD0 SCL, PD1 SDA, PD5 TXLED, PD2 STEP, PD3 STEPDIR, PD4 ICP1, PD7 INDEX
	DDRE &= ~(1 << PIN_WRITEGATE); //PE6 WRITEGATE
	DDRF &= ~((1 << PIN_TRACK0)|(1 << PIN_DSKCHANGE)); //PF4 TRACK0, PF5 WRITEPROT, PF6 DISKCHANGE, PF7 SS
	//Assign Output pins LOW "0"
	PORTB &= ~(1 << PIN_WRITEDATA);
	PORTD &= ~(1 << PIN_INDEX)|(1 << PIN_WRITEPROT);
	PORTF &= ~((1 << PIN_TRACK0)|(1 << PIN_DSKCHANGE));
	//Assign Input pins HIGH "1" (Activate Pullups)
	PORTB |= (1 << PIN_MOTORA)|(1 << PIN_SELECTA); //PB0 RXLED, PB1 SCK, PB2 MOSI, PB3 MISO, PB4 MOTORA, PB5 OCP1, PB6 SELECTA
	PORTC |= (1 << PIN_SIDE); //PC6 SIDE
	PORTD |= (1 << PIN_STEP)|(1 << PIN_STEPDIR)|(1 << PIN_READDATA); //PD0 SCL, PD1 SDA, PD5 TXLED, PD2 STEP, PD3 STEPDIR, PD4 ICP1, PD7 INDEX
	PORTE |= (1 << PIN_WRITEGATE); //PE6 WRITEGATE
	//Setup External Interrupt
	EICRA &=~((1 << ISC21)|(1 << ISC20)); //clear ISC20&ISC21 bits
	EICRA |= (1 << ISC21); //set ISC21 "falling edge"
	EIMSK |= (1 << INT2); //External Interrupt Mask Register enable INT2
#endif //defined (__AVR_ATmega32U4__)
	pinsInitialized = true; //done
	sei(); //Turn interrupts on
}

void debugPrint_P(const char *debugStr)
{
#if DEBUG && ENABLE_SERIAL
	Serial.print_P(debugStr);
	Serial.write('\n');
#endif //DEBUG && ENABLE_SERIAL
}

void debugPrintSector(char charRW, uint8_t* buffer, int16_t len)
{
#if DEBUG && ENABLE_SERIAL
	uint8_t track  = secHeader.track;
	uint8_t head   = secHeader.side;	
	uint8_t sector = secHeader.sector;

	ds.isDrive0() ? Serial.write('A'):Serial.write('B');
	Serial.write(':');
	Serial.write(charRW);
	Serial.print(track);
	Serial.write('/');
	Serial.print(head);
	Serial.write('/');
	Serial.print(sector);
	Serial.write('\n');	

	if (charRW == 'W')
	{
		int8_t bytesPerLine = 16;

		for (int i = 0; i < len; i += bytesPerLine)
		{
			Serial.printHEX( (uint8_t) (i >> 8) );
			Serial.printHEX( (uint8_t) (i & 0xFF) );
			Serial.write(':');
			//write hex values
			for (uint8_t j = 0; j < bytesPerLine; j++)
			{
				Serial.write(' ');
				Serial.printHEX(buffer[i+j]);				
			}			
			//write printable chars
			Serial.write('\t');
			for (uint8_t j = 0; j < bytesPerLine; j++)
			{
				char ch = buffer[i+j];
				if (ch >= 32 && ch < 127) Serial.write(ch);
				else Serial.write('.');
			}
			Serial.write('\n');
		}
	}
#endif //DEBUG && ENABLE_SERIAL
}

uint8_t *prepSectorBuffer(uint8_t track, uint8_t head, uint8_t sector, uint8_t seclen)
{
	uint16_t crc;
	uint8_t *buffer = secData.buffer;
	
	//prepare header
	secHeader.id = 0xFE; // ID mark
	secHeader.track = track;
	secHeader.side = head;
	secHeader.sector = sector + 1;
	secHeader.length = seclen;
	crc = calc_crc((uint8_t*)&secHeader, 5);
	secHeader.crcHI = crc >> 8;
	secHeader.crcLO = crc & 0xFF;
	secHeader.gap = 0x4E;

	//prepare sector data	
	secData.id = 0xFB;
	secData.gap = 0x4E; 		
	switch (seclen)
	{
	case 2:
		crc = calc_crc(secData.buffer, 512+1);		
		secData.crcHI = crc >> 8;
		secData.crcLO = crc & 0xFF;
		break;
	case 1:	
		if ((sector & 1) == 0) //first 256b
		{
			crc = calc_crc(secData.buffer, 256+1);
			memcpy(secData.save, secData.data+256, 3); //save first 3 bytes of second half
			secData.crcHI = crc >> 8;
			secData.crcLO = crc & 0xFF;
			memcpy(secData.data+256, &secData.crcHI, 3); //copy crc + gap over
		}
		else //second 256b
		{			
			secData.save[2] = secData.data[256 -1]; //save last byte of first half
			secData.data[256 -1] = secData.id; //copy id over			
			crc = calc_crc(secData.buffer+256, 256+1);
			secData.crcHI = crc >> 8;
			secData.crcLO = crc & 0xFF;
			buffer = secData.buffer+256;	
		}
		break;
	default:
		debugPrint_P(err_secSize);		
	}
	debugPrintSector('R', NULL, 0);
	return buffer;
}
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

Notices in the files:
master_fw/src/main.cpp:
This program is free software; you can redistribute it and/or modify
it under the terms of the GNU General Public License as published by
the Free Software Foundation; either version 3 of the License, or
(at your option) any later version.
